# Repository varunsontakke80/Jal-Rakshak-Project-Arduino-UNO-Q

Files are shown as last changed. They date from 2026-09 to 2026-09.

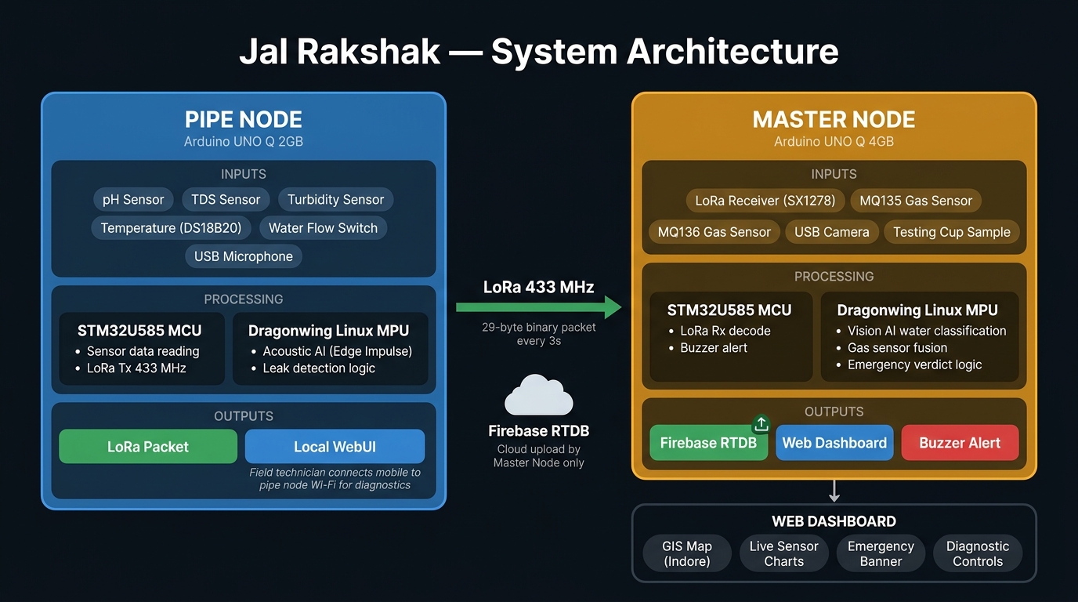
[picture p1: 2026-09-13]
Images/Jal_Rakshak_System_Architecture_v3.jpg

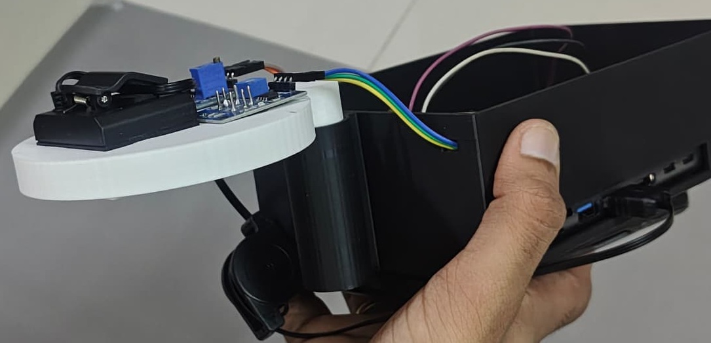
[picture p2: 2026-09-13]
Images/Data collectionsetup MN.jpeg

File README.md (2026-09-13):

# 💧 Jal Rakshak: AI-Powered Municipal Water Security & Pipeline Integrity Network

**Jal Rakshak** ("Water Protector") is a decentralized, dual-tier physical AI water security and acoustic leak detection system designed to safeguard municipal drinking water distribution networks against underground transit contamination, sewage cross-ingress, and silent pipeline bursts.

Addressing the critical "last-mile" vulnerability between centralized water treatment plants and residential taps, Jal Rakshak continuously monitors subterranean pipes using autonomous edge nodes and provides municipal field engineers with a handheld AI diagnostic gateway terminal.

---

## 📌 System Architecture & Core Concept

Municipal water networks frequently suffer from negative pressure events, soil shifting, and aging infrastructure. When an underground potable water pipe develops a leak adjacent to a sewage line or open drain, contaminated water is siphoned into the drinking supply.

Jal Rakshak eliminates reliance on delayed manual complaints and sporadic lab tests through a two-tier physical AI architecture:

```text
+-------------------------------------------------------------------------+
|                      Underground Pipe Node (Field)                      |
|  - ESP32 Dual-Core Controller (Solar / Battery / Energy Harvesting)     |
|  - INMP441 I2S Microphone -> TinyML 1D-CNN (Acoustic Leak Detection)    |
|  - Multi-Sensor Array: pH, Temp-Compensated TDS, Turbidity, Temp, Flow  |
|  - SX1278 LoRa Transceiver (433 MHz Binary Telemetry Uplink)            |
+-------------------------------------------------------------------------+
                                    │
                         [ 433 MHz LoRa Radio Link ]
                         [ 28-Byte Packed Struct   ]
                                    │
                                    ▼
+-------------------------------------------------------------------------+
|                  Jal Rakshak Master Node (Central Gateway)              |
|                                                                         |
|  [STM32U585 MCU (Zephyr RTOS)]                                          |
|   - Hard Real-Time LoRa Telemetry Ingestion (SX1278 SPI)                |
|   - Dual Gas Sensing (12-bit ADC): MQ135 (NH3) & MQ136 (H2S)            |
|   - Hardware Alert Buzzer & RouterBridge Inter-Core RPC Server          |
|                                                                         |
|  [Qualcomm Dragonwing Linux MPU (Arduino App Lab)]                      |
|   - Edge Impulse Vision-AI Image Classifier (MobileNet EIM)             |
|   - Forensic Testing Cup: UV Fluorescence Analysis                      |
|   - Water Quality Multi-Parametric Safety Verdict Engine                |
|   - Interactive WebUI Dashboard on Port 7000 (Leaflet GIS + Live Charts)|
+-------------------------------------------------------------------------+
```

---

## 🧠 Dual Edge AI Intelligence

Jal Rakshak runs two dedicated machine learning models trained via Edge Impulse directly on edge hardware:

1. **TinyML Acoustic Leak Detection (Pipe Node):**
   - **Hardware:** ESP32 (Core 0, FreeRTOS).
   - **Input:** 16 kHz acoustic vibration stream from an INMP441 I2S MEMS microphone clamped to the pipeline.
   - **Model:** 1D-CNN with MFE/MFCC feature extraction distinguishing background urban traffic noise from the high-frequency acoustic hiss of a pressurized pipe leak.
   - **Latency & Performance:** <20 ms inference latency with high energy efficiency on battery power.

2. **Vision-AI Water Quality Classification (Master Node):**
   - **Hardware:** Qualcomm Dragonwing Linux MPU on the Arduino UNO Q.
   - **Input:** Live camera feed from an enclosed testing cup under controlled UV illumination.
   - **Model:** MobileNet transfer-learning vision classifier (`Jal-Rakshak-Water-Quality-Vision`) deployed as a Linux aarch64 EIM executable.
   - **Function:** Detects organic sewage fluorescence, turbidity shifts, and visible contamination that standard electrochemical probes cannot identify.

---

## 📁 Project Structure & File Guide

The repository is organized by subsystem, hardware engineering files, AI models, and documentation assets:

```text
Jal Rakshak/
├── README.md                           # This project documentation
├── Edge AI Models/                     # Standalone compiled Edge Impulse model artifacts (.eim)
├── Images/                             # Architecture diagrams, flowcharts, and hardware photos
├── Master Node/                        # Arduino UNO Q Gateway & Diagnostic Terminal workspace
├── Pipe Node/                          # Underground monitoring node workspace
└── Video/                              # Demonstrations and AI training process recordings
```

### 1. `Master Node/` (Central Gateway & Field Terminal)
* **`Code Files/Master Node APP/`**: Complete Arduino App Lab application for the Arduino UNO Q:
  * `app.yaml`: App Lab application manifest specifying the Python base environment and Edge Impulse video classification brick (`ei-model-1087722-1`).
  * `python/main.py`: Central coordination server, RouterBridge RPC client, multi-sensor verdict logic, and WebSocket broadcaster.
  * `python/config.py`: Thresholds for WHO drinking water standards (pH, TDS, Turbidity, NH₃, H₂S), pinouts, and network configurations.
  * `sketch/sketch.ino`: High-performance Zephyr RTOS firmware for the STM32U585 MCU. Handles SX1278 LoRa reception, MQ135/MQ136 gas ADC sampling, active buzzer alert control, and RouterBridge RPC endpoints.
  * `sketch/sketch.yaml`: Arduino sketch dependency configuration specifying platform and libraries.
  * `assets/`: Web dashboard frontend (`index.html`, `style.css`, `app.js`) featuring real-time GIS pipe map, live telemetry graphs, and forensic testing cup controls.
* **`Code Files/Master Node APP.zip`**: Compressed App Lab package ready for direct import into the Arduino App Lab IDE.
* **`PCB Files/`**:
  * `Schematic_Jal-Rakshak-Master-Node_2026-09-11.png`: Complete Master Node electrical schematic.
  * `PCB_Jal Rakshak Master node.png`: Board layout and trace routing diagram.
  * `Jal Rakshak master Node PCB traces to print.pdf`: Printable 1:1 scale PCB artwork for chemical etching.
* **`CAD Files/`**:
  * `Jal Rakshak Master Node Case.3mf`: 3D printable chassis for the Arduino UNO Q, testing cup chamber, and sensor mountings.
  * `Master Node CAD image.png`, `Slicing SS1.png`, `Slicing SS2.png`: 3D renders and slicer configurations.
* **`Steps to assembly/`**: Step-by-step photographic assembly guide (1.jpeg – 14.jpeg, PCB photos) for component soldering, wiring, and enclosure fitting.
* **`Master Node components.jpeg`**: Photographic overview of all Master Node hardware components.

### 2. `Pipe Node/` (Underground Sensing Station)
* **`Code Files/JalRakshakPipeNode/`**:
  * `sketch/sketch.ino`: ESP32 firmware integrating the Edge Impulse acoustic inference library, analog sensor acquisition (pH, TDS, Turbidity, DS18B20 1-Wire temperature), optical water presence sensing, and 28-byte binary LoRa transmission.
  * `sketch/sketch.yaml`: Dependency configuration for the ESP32 platform.
* **`Code Files/JalRakshakPipeNode.zip`**: Ready-to-deploy archive of the Pipe Node firmware.
* **`PCB Files/`**:
  * `Schematic_Jal-Rakshak-Pipe-Node_2026-09-11.png`: Sensor integration and power management schematic.
  * `Sensor PCB Front.jpg` & `Sensor PCB Back.jpg`: High-resolution photographs of the custom double-sided sensor conditioning board.
* **`CAD Files/`**:
  * `Pipe Node sensor case Final Design.3mf`: In-pipe waterproof sensor chamber for water immersion probes.
  * `Pipe_Node_PCB and MIC Case.3mf`: External acoustic clamp housing holding the ESP32, LoRa module, and INMP441 microphone against the pipe wall.
  * `Pipe Node Sensor Case.png`, `Pipe node Case .png`, `Slicing SS 1.png`, `Slicing SS 2.png`: 3D CAD visualizations and slicing guidelines.
* **`Sound data/`**:
  * `water leak sounds/`: Recorded audio dataset of pressurized water pipe pinhole and crack leaks used for model training.
  * `Noise/`: Environmental baseline recordings (traffic noise, soil dampening, motor hums) used for negative training samples.
* **`Steps to assembly/`**: Comprehensive assembly photographic log (1.jpeg – 20.jpeg, EdgeAI setup guides) showing probe sealing, pipe clamp mounting, and PCB assembly.
* **`Pipe Node Componenets.jpeg` & `Pipe Node sensors.jpeg`**: Visual inventory of all Pipe Node electronics, probes, and mechanical hardware.

### 3. `Edge AI Models/`
* **`jal-rakshak-acoustic-leak-detection-linux-aarch64-v12-impulse-#1.eim`**: Edge Impulse acoustic classification model compiled for aarch64 Linux systems.
* **`jal-rakshak-water-quality-vision-linux-aarch64-v3-impulse-#1.eim`**: Edge Impulse vision classification model compiled for the Qualcomm Dragonwing MPU on the Arduino UNO Q.

### 4. `Images/`
* High-resolution system diagrams and visuals:
  * `Jal_Rakshak_System_Architecture_v3.jpg`: Full end-to-end hardware and network architecture diagram.
  * `Jal_Rakshak_Master_Node_Code_Flowchart.jpg` / `.png`: Operational flow of the dual-processor Master Node firmware and Python runtime.
  * `Jal_Rakshak_Pipe_Node_Code_Flowchart.jpg`: Sensing, TinyML inference, and LoRa transmission logic of the Pipe Node.
  * `Bhagirathpura.png`, `pipeblast.png`, `pipeblast3.png`: Ground truth case study photos demonstrating urban pipeline failure mechanisms.
  * `lorapic.jpg`, `USBc Mic.png`, `Usb C hub.png`, `usb cam.png`, `Data collectionsetup MN.jpeg`: Peripheral and lab testing setup photos.

### 5. `Video/`
* **`Master Node Edge AI making.mp4`**: Demonstration of the Master Node testing cup setup, camera alignment, and Edge Impulse model deployment.
* **`Pipe Node Edge AI Data Collection Process.mp4`**: Acoustic data recording methodology, sensor pod immersion testing, and model training workflow.

---

## 🔌 Hardware Bill of Materials (BOM)

| Subsystem | Component | Specifications / Role |
|---|---|---|
| **Master Gateway** | **Arduino UNO Q (ABX00087)** | Dual-core processor: STM32U585 MCU (Cortex-M33) + Qualcomm Dragonwing Linux MPU |
| **Master Gateway** | **SX1278 LoRa Module (Ra-01)** | 433 MHz SPI LoRa transceiver for long-range packet reception |
| **Master Gateway** | **USB 2.0 HD Camera** | Testing Cup Vision-AI sample image acquisition |
| **Master Gateway** | **UV LED Array (395–405 nm)** | Fluorescent excitation of organic sewage matter |
| **Master Gateway** | **MQ135 Gas Sensor** | Airborne Ammonia ($NH_3$) and sewage gas marker detection |
| **Master Gateway** | **MQ136 Gas Sensor** | Hydrogen Sulfide ($H_2S$) toxic sewage gas detection |
| **Master Gateway** | **5V Active Buzzer** | High-decibel audible emergency alarm for contamination alerts |
| **Pipe Node** | **ESP32 Development Board** | 240 MHz dual-core microcontroller with FreeRTOS |
| **Pipe Node** | **INMP441 I2S MEMS Mic** | Ultra-low noise digital microphone clamped to pipe wall for acoustic leak sensing |
| **Pipe Node** | **SX1278 LoRa Module (Ra-01)** | 433 MHz SPI LoRa transceiver for subterranean packet transmission |
| **Pipe Node** | **Analog pH Sensor & Probe** | Electrochemical hydrogen-ion activity measurement (0–14 pH) |
| **Pipe Node** | **Analog TDS Sensor Kit** | Total Dissolved Solids / mineral conductivity measurement (0–1000 ppm) |
| **Pipe Node** | **Optical Turbidity Sensor** | Nephelometric suspended particulate detection (0–3000 NTU) |
| **Pipe Node** | **DS18B20 Temp Sensor** | Stainless-steel waterproof 1-Wire sensor for dynamic TDS temperature compensation |
| **Pipe Node** | **Optical Liquid Level Sensor** | Non-invasive verification of water presence vs. air-pocket dry conditions |
| **Power** | **3.7V 18650 / LiPo Cells + Solar** | Lithium battery buffering paired with solar/mini-hydro energy harvesting |
| **Enclosures** | **Custom 3D-Printed Housings** | In-pipe water-sealed sensor chamber & external acoustic clamp chassis |

---

## 🚀 Deployment & Operation

### 1. Flashing the Underground Pipe Node (ESP32)
1. Open the Arduino IDE and ensure the **ESP32 by Espressif Systems** board package is installed.
2. Open the sketch located at:
   ```text
   Pipe Node/Code Files/JalRakshakPipeNode/sketch/sketch.ino
   ```
3. Install required libraries via the Arduino Library Manager:
   - `LoRa` (by Sandeep Mistry)
   - `OneWire` & `DallasTemperature`
   - Edge Impulse inferencing library
4. Select board **ESP32 Dev Module**, verify GPIO connections to the sensors and LoRa transceiver, and flash over USB.

### 2. Running the Master Node (Arduino UNO Q)
1. Connect the **Arduino UNO Q** to your local network via Wi-Fi or Ethernet.
2. Launch **Arduino App Lab** and open the application directory:
   ```text
   Master Node/Code Files/Master Node APP
   ```
3. Arduino App Lab automatically parses `app.yaml`, launches the `python-apps-base` container, and initialises the `ei-models-runner` container with the Edge Impulse vision model.
4. The STM32U585 sketch (`sketch/sketch.ino`) is automatically compiled and uploaded to the MCU over the internal bridge.
5. Open your web browser on any device on the same local network:
   ```text
   http://<arduino-uno-q-ip>:7000
   ```
6. The dashboard displays real-time telemetry from up to 4 pipe nodes, live gas concentration values, and interactive controls for the forensic water testing cup.

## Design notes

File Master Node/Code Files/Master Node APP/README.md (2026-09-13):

# 💧 Jal Rakshak Master Node : Decentralized Water Quality Monitoring System
## Master Node Application — Arduino App Lab Bricks

> Real-Time Water Quality Forensic Gateway & Underground Pipeline Network Monitor.  

---

## 🌟 Overview & Features

This project connects the **Qualcomm Dragonwing MPU (Linux)** and **STM32U585 MCU** on the Arduino UNO Q with containerized App Lab Bricks:

1. **`arduino:video_image_classification` Brick**:
   - Runs live video classification using your custom Edge Impulse trained model (`good_water` vs `bad_water`).
   - Streams live camera video feed directly on port `4912` (`/embed`) with bounding boxes/classification overlays.
2. **`arduino:web_ui` Brick**:
   - Hosts a mobile-responsive WebSocket dashboard directly on port `7000` from `assets/`.
   - Access from your smartphone, tablet, or PC browser: `http://<board-ip>:7000`.
3. **Dual-Core STM32 MCU & RouterBridge**:
   - **LoRa 433 MHz** receiver for Pipe Nodes 1–4 telemetry (pH, TDS, turbidity, temperature, leak acoustic alert, emergency flags).
   - **MQ135 (NH₃)** and **MQ136 (H₂S)** gas sensors for biochemical sewage contamination detection.
   - **Buzzer** alarm control.
4. **Google Firebase Realtime Database**:
   - Real-time cloud synchronization for pipeline nodes and forensic water test logs.

---

## 📱 Mobile Web Access (Same WiFi)

1. Connect your phone or laptop to the same WiFi network as your Arduino UNO Q.
2. Open your mobile browser and navigate to:
   ```
   http://<board-ip>:7000
   ```
   *(Example: `http://192.168.1.50:7000` or `http://arduino-uno-q.local:7000`)*

---

## 📁 Project Structure

```
Master Node APP/
├── app.yaml               # App Lab manifest (declares video_image_classification & web_ui bricks)
├── README.md              # Project documentation and deployment guide
│
├── sketch/                # MCU Firmware (STM32U585)
│   ├── sketch.ino         # LoRa SX1278 (433MHz), MQ135/136 ADC, Buzzer, RouterBridge
│   └── sketch.yaml        # Board profile (arduino:zephyr) and pinned library dependencies
│
├── python/                # MPU Application (Qualcomm Dragonwing Linux)
│   ├── main.py            # App Lab Bricks coordinator, RouterBridge listener, Firebase uplink, App.run()
│   ├── config.py          # Firebase Realtime Database credentials
│   └── requirements.txt   # Python dependencies (requests)
│
├── assets/                # WebUI Brick Frontend (served on Port 7000)
│   ├── index.html         # Responsive tabbed dashboard (Pipe Nodes, Water Cup Test, Diagnostics)
│   ├── style.css          # Dark-theme mobile-first stylesheet
│   ├── app.js             # WebUI client (WebSocket events, threshold slider, gas trigger)
│   ├── libs/
│   │   ├── arduino.js     # Official Arduino WebUI client SDK
│   │   └── socket.io.min.js
│   └── img/               # Icons and graphics
│
└── models/                # Edge Impulse ML Models
    └── auqtest-linux-aarch64-v1-impulse-#1.eim   # Custom water quality model
```

---

## 🔌 Hardware Wiring & Pin Mapping

| Peripheral | Board Pin | Type | Function |
|---|---|---|---|
| **LoRa SCK** | D13 | SPI | SX1278 SPI Clock |
| **LoRa MISO** | D12 | SPI | SX1278 SPI MISO |
| **LoRa MOSI** | D11 | SPI | SX1278 SPI MOSI |
| **LoRa CS (NSS)** | D10 | GPIO | Chip Select |
| **LoRa RST** | D9 | GPIO | Reset |
| **LoRa DIO0** | D2 | GPIO (Interrupt) | Packet Received Flag |
| **MQ135 (Ammonia)** | A0 | Analog ADC (3.3V) | NH₃ Gas Sensor (via 10k/20k divider) |
| **MQ136 (H₂S)** | A1 | Analog ADC (3.3V) | H₂S Gas Sensor (via 10k/20k divider) |
| **Buzzer** | D7 | Digital Output | Active Alarm (HIGH = ON) |
| **USB Camera** | USB-C Hub | V4L2 USB | Water Testing Cup Visual AI |

> ⚠️ **Voltage Note**: The STM32U585 GPIOs operate at **3.3V**. Ensure MQ sensors use the 10kΩ + 20kΩ voltage divider from the 5V sensor output.

---

## 🚀 How to Run in Arduino App Lab

### Step 1 — Open the App in App Lab IDE
1. Connect your **Arduino UNO Q** to your computer via USB-C.
2. Launch the **Arduino App Lab** application.
3. Click **Open App** and select the `Master Node APP` folder.

### Step 2 — Model Setup
- In App Lab, the `app.yaml` will automatically detect the `video_image_classification` Brick.
- You can select your imported Edge Impulse water model (`auqtest-linux-aarch64-v1-impulse-#1`) in the brick settings.

### Step 3 — Configure Cloud Database
- Edit `python/config.py` with your Firebase Realtime Database URL & secret key.

### Step 4 — Run!
- Click the **Run** button at the top of App Lab.
- App Lab compiles the MCU sketch, launches the Brick containers, and opens the Web UI.
- On your phone, visit `http://<board-ip>:7000` to interact with the system live!

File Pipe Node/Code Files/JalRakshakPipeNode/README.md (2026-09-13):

# Jal Rakshak Pipe Node — Application Architecture & Code Structure

**Platform:** Arduino UNO Q (Dual-Processor: Qualcomm Dragonwing QRB2210 MPU + STM32U585 MCU)

---

## 1. System Overview

The **Jal Rakshak Pipe Node** is an intelligent, edge-computing underground water security monitor installed directly along municipal pipeline segments. It combines:
1. **Multi-Parameter Physical Sensor Acquisition** on the STM32 MCU.
2. **Sub-surface Acoustic Leak Detection** using Edge AI (TinyML) on the Qualcomm Dragonwing Linux MPU.
3. **Long-Range Telemetry Uplink** via 433 MHz LoRa to the Master Node Gateway.
4. **Local Mobile Diagnostic WebUI** on port 7000 for field technician maintenance without requiring internet access.

> **CRITICAL ARCHITECTURAL DESIGN**: All field telemetry is transmitted exclusively via LoRa (SX1278) to the Master Node, which handles cloud synchronisation.

---

## 2. Dual-Processor Division of Responsibility

| Subsystem | Processor | Environment | Key Responsibilities |
| :--- | :--- | :--- | :--- |
| **Microcontroller (MCU)** | STM32U585 (ARM Cortex-M33) | Zephyr RTOS / Arduino C++ (sketch/) | Real-time ADC sensor sampling (pH, TDS, Turbidity, Temp, Flow switch); LoRa SX1278 binary packet serialization & RF transmission; RouterBridge RPC endpoints. |
| **Microprocessor (MPU)** | Qualcomm Dragonwing QRB2210 (Quad Cortex-A53, 2GB RAM) | Debian Linux / Python 3.13 (python/) | High-speed audio capture via ALSA (plughw:0,0); continuous Edge Impulse inference (Leak vs Noise); temporal alert filtering; diagnostic WebSocket WebUI. |

---

## 3. Communication Interface (RouterBridge RPC)

The MPU and MCU communicate via high-speed shared memory RPC (Arduino_RouterBridge):

- **
ead_sensors()** (MCU provides, MPU calls every 3s):
  Returns CSV string: 
odeId,latitude,longitude,ph,tds,turbidity,temperature,waterPresence,leakAlert,emergencyFlag
- **leak_alert(bool)** (MPU notifies MCU):
  Triggered when Edge AI detects acoustic cavitation/leak with $\ge 75\%$ confidence for 2 consecutive windows. Causes MCU to immediately assert the emergency flag and force an unscheduled LoRa transmission.
- **	rigger_lora_tx** (MPU notifies MCU):
  Allows field technicians to trigger an immediate manual LoRa transmission test from the diagnostic WebUI.
- **sensor_update** (MCU notifies MPU):
  Emitted after every periodic LoRa transmission so the local WebUI reflects the exact telemetry sent to the Master Node.

---

## 4. File Structure

`	ext
JalRakshakPipeNode/
├── app.yaml               # App Lab manifest (audio_classification & web_ui bricks)
├── README.md              # Complete architecture and operation documentation
├── assets/
│   ├── index.html         # Responsive diagnostic dashboard HTML
│   ├── style.css          # Dark-mode industrial cyber-clean CSS
│   ├── app.js             # Client WebSocket telemetry & Edge AI bar animator
│   └── libs/
│       ├── arduino.js     # Official Arduino App Lab WebUI client
│       └── socket.io.min.js# Offline Socket.IO client library
├── models/
│   └── README.md          # Edge Impulse project & class documentation
├── python/
│   ├── main.py            # Main MPU application (AI inference hook & bridge logic)
│   └── config.py          # Node identity & deployment parameters
└── sketch/
    ├── sketch.ino         # STM32 MCU firmware (ADC acquisition & LoRa driver)
    └── sketch.yaml        # Zephyr platform & library dependency manifest
`

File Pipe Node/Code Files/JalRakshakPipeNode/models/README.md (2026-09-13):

# Jal Rakshak Pipe Node — Edge AI Acoustic Leak Detection Model

This folder documents the Edge Impulse model configuration for the underground acoustic leak detection system running on the Arduino UNO Q (Qualcomm Dragonwing QRB2210 MPU, Linux aarch64).

---

## 1. Edge Impulse Project Details

- **Project Name:** Jal-Rakshak-Acoustic-Leak-Detection
- **Owner / Project ID:** 
arunsontakke80 / 1022382
- **Deployment Version:** 
11 (ei-model-1022382-1)
- **Application:** Real-time acoustic frequency analysis of pipe vibrations to detect subterranean water leaks and cavitation
- **Target Hardware:** Arduino UNO Q (Qualcomm Dragonwing QRB2210, Linux aarch64)
- **Input Peripheral:** USB Microphone on ALSA hardware card plughw:0,0

---

## 2. Model Classes & Classification

The trained model classifies 1-second audio windows into 2 distinct classes:

| Class | Label in EI | Description | System Action |
|---|---|---|---|
| **1** | Leak | Acoustic signature of pressurized water escaping a pipe fissure, cavitation hiss, or turbulent pipe breach | Increment consecutive counter; trigger emergency LoRa packet when confidence >= 75% for 2 consecutive windows |
| **2** | Noise | Normal ambient background sound, pump hum, laminar water flow, or surface environmental noise | Clear leak alert status; maintain normal telemetry cycle |

---

## 3. Impulse Design Parameters

- **Time series data:** 1000 ms (1.0 s) window size, 500 ms sliding window stride
- **Frequency:** 16,000 Hz (16 kHz), 1 channel (mono)
- **Input Features:** 16,000 features per inference window
- **DSP Block:** MFE (Mel-Frequency Energy)
- **Learning Block:** 1D / 2D Convolutional Neural Network (continuous audio classification)

---

## 4. App Lab Architecture & Continuous Inference

In Arduino App Lab, the rduino:audio_classification brick:
1. Automatically launches the Edge Impulse runner container (ei-audio-classifier-runner:1337).
2. Streams audio captured from ALSA plughw:0,0 (16 kHz mono) into the model.
3. python/main.py hooks sc.infer_from_features to intercept every single inference slice (~400 ms) directly from the runner.
4. Raw probabilities for both Leak and Noise are streamed in real time over WebSocket to the local diagnostic WebUI (http://<ip>:7000).
5. When Leak >= 0.75 for 2 consecutive windows, python/main.py notifies the STM32 MCU via Bridge RPC (leak_alert), forcing an immediate emergency LoRa transmission to the Master Node.

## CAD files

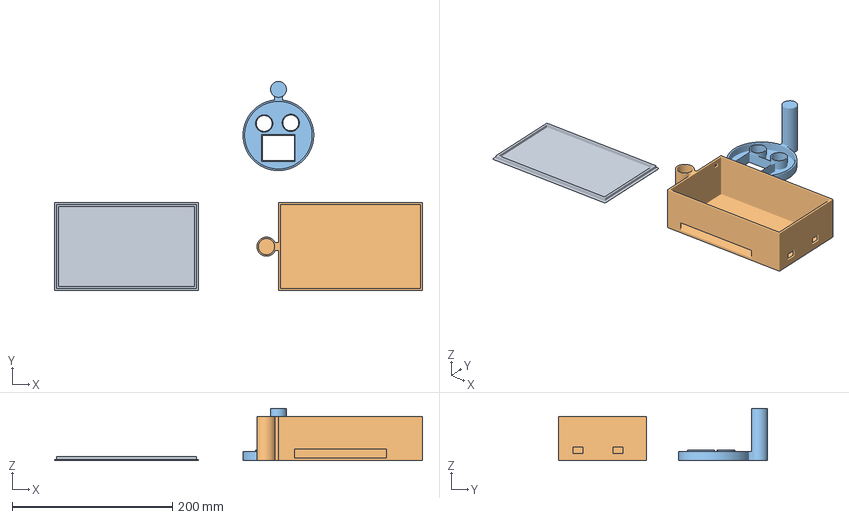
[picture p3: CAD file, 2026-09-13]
Master Node/CAD Files/Jal Rakshak Master Node Case.3mf
460.0 x 261.6 x 65.0 mm

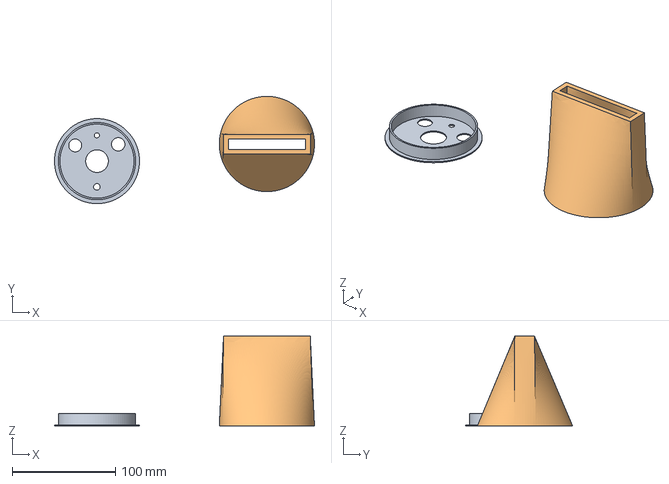
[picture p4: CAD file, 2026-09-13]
Pipe Node/CAD Files/Pipe Node sensor case Final Design.3mf
252.3 x 104.1 x 87.0 mm

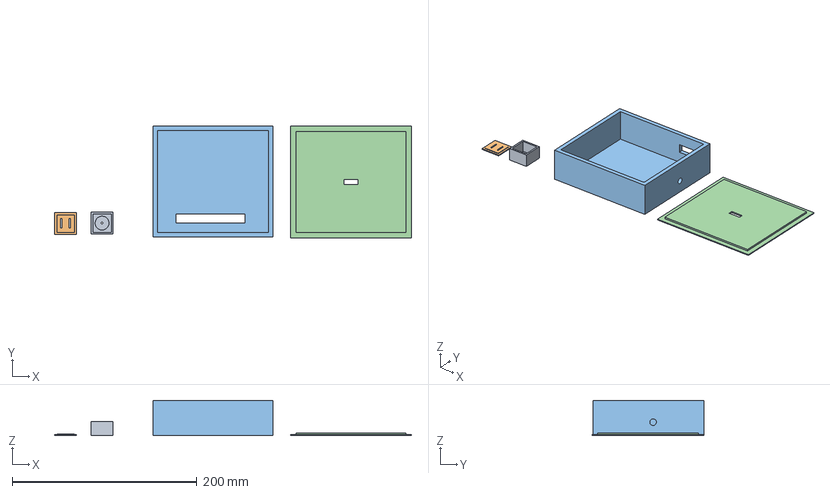
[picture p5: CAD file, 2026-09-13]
Pipe Node/CAD Files/Pipe_Node_PCB and MIC Case.3mf
386.5 x 121.0 x 38.0 mm

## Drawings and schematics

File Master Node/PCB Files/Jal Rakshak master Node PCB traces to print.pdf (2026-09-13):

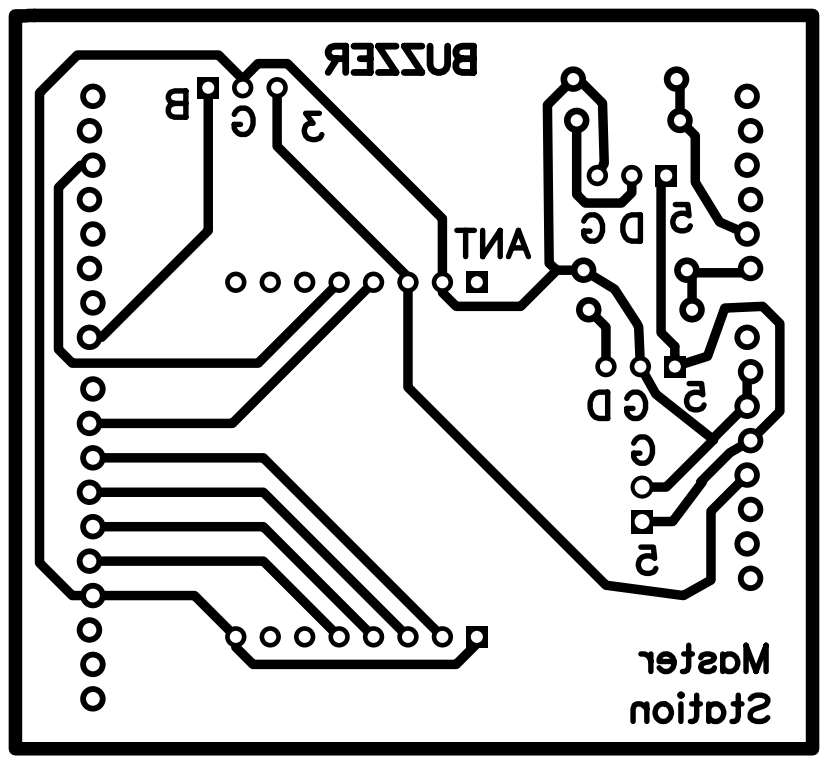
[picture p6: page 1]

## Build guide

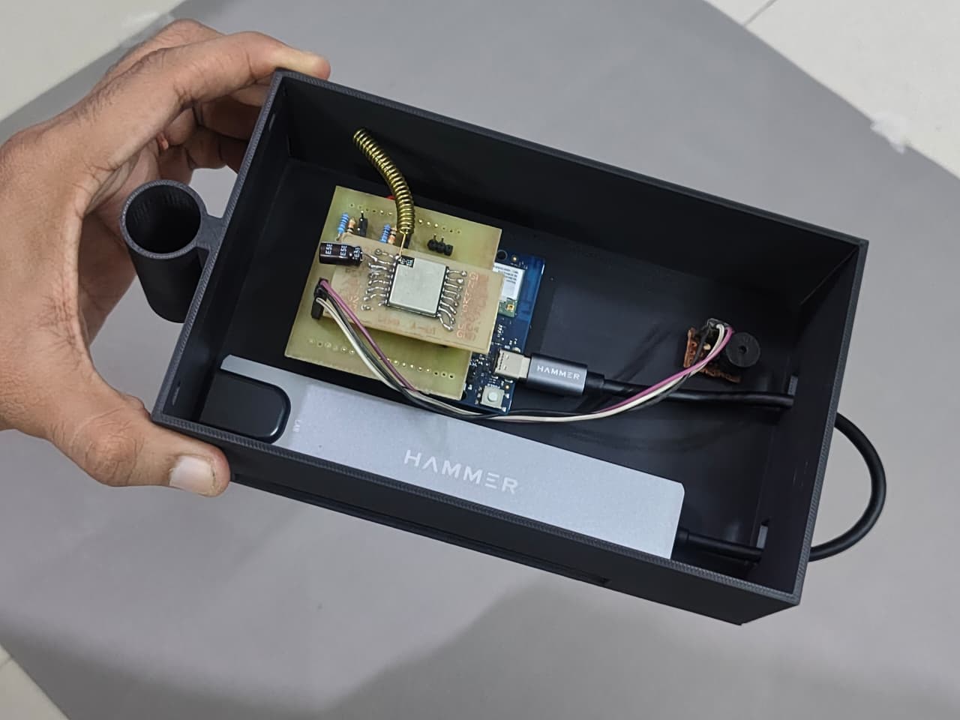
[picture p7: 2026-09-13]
Master Node/Steps to assembly/8.jpeg

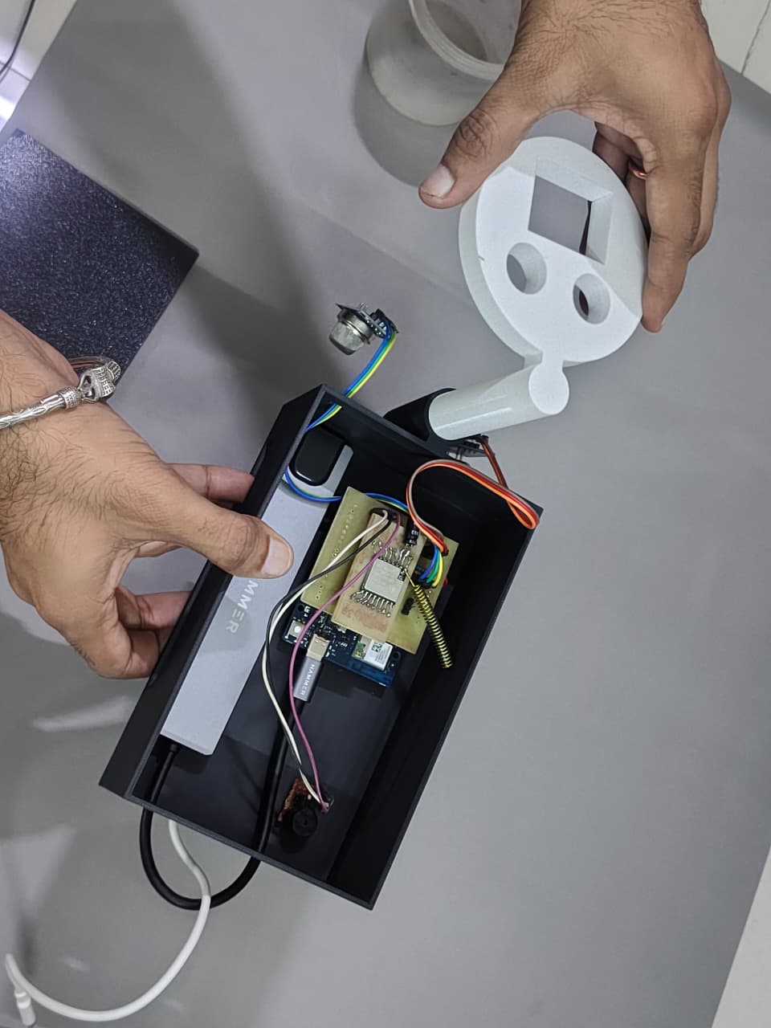
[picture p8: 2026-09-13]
Master Node/Steps to assembly/11.jpeg

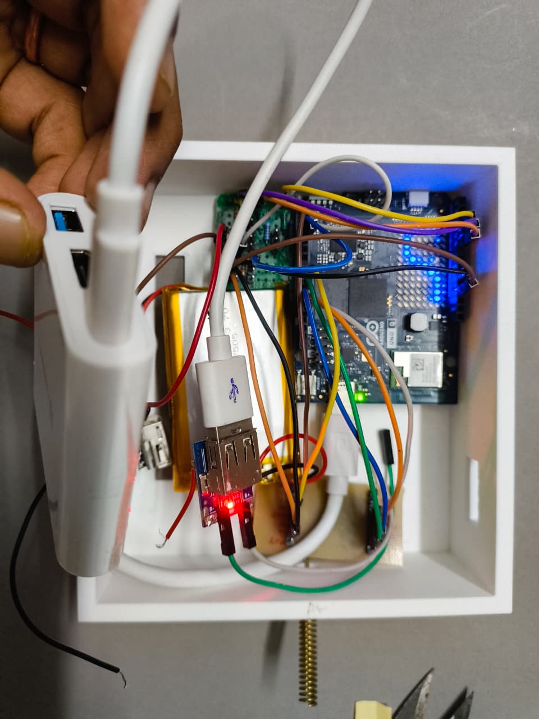
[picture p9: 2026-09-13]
Pipe Node/Steps to assembly/16.1.jpeg

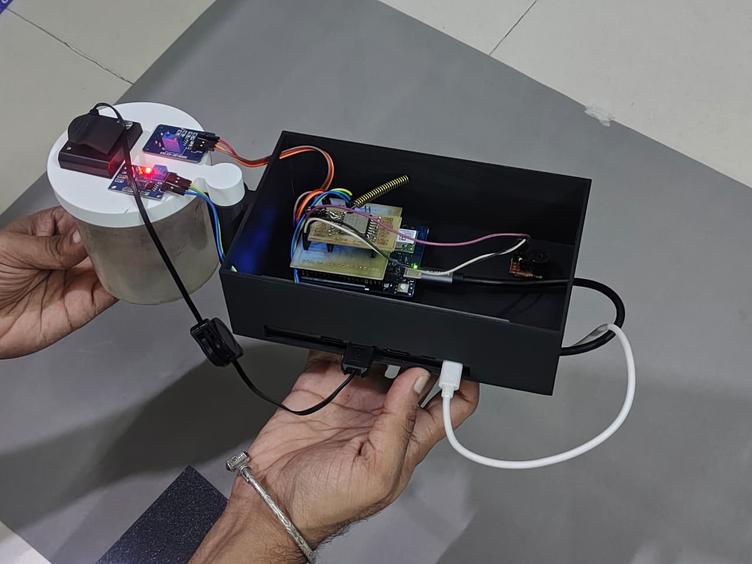
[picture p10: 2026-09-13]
Master Node/Steps to assembly/12.jpeg

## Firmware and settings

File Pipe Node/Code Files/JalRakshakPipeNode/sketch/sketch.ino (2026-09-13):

/**
 * Jal Rakshak Pipe Node — Arduino UNO Q (STM32U585 MCU, Zephyr RTOS)
 *
 * Responsibilities (MCU side):
 *   - Read water quality sensors: pH (A0), TDS (A1), Turbidity (A2)
 *   - Read DS18B20 water temperature via 1-Wire (D4)
 *   - Detect water flow switch (D3, interrupt)
 *   - Transmit 28-byte binary TelemetryPayload over LoRa (SX1278, 433 MHz)
 *   - Expose Bridge RPC endpoints for MPU (main.py) to:
 *       - read_sensors()    → returns CSV of all sensor values
 *       - trigger_lora_tx() → forces an immediate LoRa transmission
 *   - Receive leak_alert notifications from MPU (acoustic AI result)
 *     and fold leakAlert flag into the next LoRa transmission
 *
 * Sensors pinout (all analog sensors must go through 10k/20k voltage divider
 * because sensors output 0-5V but UNO Q ADC pins are 3.3V max):
 *   A0 = pH sensor (analog, 0-5V scaled to 0-3.3V)
 *   A1 = TDS sensor (analog, 0-5V scaled to 0-3.3V)
 *   A2 = Turbidity sensor (analog, 0-5V scaled to 0-3.3V)
 *   D4 = DS18B20 data (1-Wire, 4.7k pull-up to 3.3V)
 *   D3 = Water flow switch (digital input, interrupt on CHANGE)
 * LoRa SX1278 (SPI):
 *   D13 = SCK, D12 = MISO, D11 = MOSI, D10 = CS, D9 = RST, D2 = DIO0
 *
 * Author: Varun Sontakke — Jal Rakshak Project
 */

#include <SPI.h>
#include <LoRa.h>
#include <OneWire.h>
#include <DallasTemperature.h>
#include <Arduino_RouterBridge.h>

// ── LoRa SX1278 Pinout ─────────────────────────────────────────────────────
#define LORA_SCK    13
#define LORA_MISO   12
#define LORA_MOSI   11
#define LORA_CS     10
#define LORA_RST     9
#define LORA_DIO0    2

// ── Water Quality Sensor Pins (analog, through voltage divider) ─────────────
#define PIN_PH          A0
#define PIN_TDS         A1
#define PIN_TURBIDITY   A2
#define PIN_DS18B20     4   // 1-Wire data, 4.7k pull-up to 3.3V
#define PIN_FLOW_SWITCH 3   // Digital input w/ interrupt

// ── ADC & voltage constants ─────────────────────────────────────────────────
#define VOLTAGE_RESOLUTION      3.3f
#define ADC_MAX                 4095.0f  // 12-bit ADC
// The voltage divider (10kΩ top / 20kΩ bottom) makes Vadc = Vsensor * (20/(10+20)) = 0.667 * Vsensor
// So Vsensor = Vadc * 1.5  (multiply measured voltage by 1.5 to recover true 0-5V sensor output)
#define VOLTAGE_DIVIDER_FACTOR  1.5f

// ── pH calibration ──────────────────────────────────────────────────────────
#define PH_M    -5.70f
#define PH_B    17.24f

// ── Node Identity ───────────────────────────────────────────────────────────
#define NODE_ID       1          // Change to 2/3/4 for other nodes
#define NODE_LAT      22.7196f   // Update GPS for deployment location
#define NODE_LON      75.8577f

// ── Telemetry timing ────────────────────────────────────────────────────────
#define TELEMETRY_INTERVAL_MS  3000   // 3-second heartbeat LoRa Tx
#define SENSOR_SAMPLE_COUNT    5      // Oversample & average for noise rejection

// ── TelemetryPayload struct (packed binary for LoRa) ───────────────────────
#pragma pack(push, 1)
struct TelemetryPayload {
    uint8_t  nodeId;        // 1 byte
    float    latitude;      // 4 bytes
    float    longitude;     // 4 bytes
    float    ph;            // 4 bytes
    float    tds;           // 4 bytes
    float    turbidity;     // 4 bytes
    float    temperature;   // 4 bytes
    bool     waterPresence; // 1 byte
    bool     leakAlert;     // 1 byte
    bool     emergencyFlag; // 1 byte
    // Total = 28 bytes
};
#pragma pack(pop)

// ── Sensor objects ──────────────────────────────────────────────────────────
OneWire oneWire(PIN_DS18B20);
DallasTemperature ds18b20(&oneWire);

// ── Shared state ────────────────────────────────────────────────────────────
volatile bool waterPresence    = true;     // Default: active flow in pipe (safe baseline)
bool          leakAlert        = false;    // Set by MPU Bridge notify
bool          forceTx          = false;    // Force immediate LoRa Tx
unsigned long lastTxMs         = 0;

// ── Flow switch interrupt (standard Arduino ISR on STM32 / Zephyr) ───────────
void onFlowChange() {
    waterPresence = (digitalRead(PIN_FLOW_SWITCH) == LOW);
}

// ── ADC helpers ─────────────────────────────────────────────────────────────
float readVoltageSensor(int pin) {
    long sum = 0;
    for (int i = 0; i < SENSOR_SAMPLE_COUNT; i++) {
        sum += analogRead(pin);
        delayMicroseconds(200);
    }
    float raw = (float)sum / SENSOR_SAMPLE_COUNT;
    float vadc = (raw / ADC_MAX) * VOLTAGE_RESOLUTION;    // ADC voltage (0-3.3V)
    float vsensor = vadc * VOLTAGE_DIVIDER_FACTOR;         // True sensor voltage (0-5V)
    return vsensor;
}

// ── pH conversion ───────────────────────────────────────────────────────────
float readPH() {
    float v = readVoltageSensor(PIN_PH);
    // When probe is disconnected or floating (open-circuit near 0V or >4.85V),
    // default to normal safe drinking water pH (7.24)
    if (v < 0.25f || v > 4.85f) {
        return 7.24f;
    }
    float ph = PH_M * v + PH_B;
    ph = constrain(ph, 0.0f, 14.0f);
    return ph;
}

// ── TDS conversion (with temperature compensation) ──────────────────────────
float readTDS(float tempC) {
    float v = readVoltageSensor(PIN_TDS);
    // When probe is disconnected (open-circuit near 0V or >4.85V),
    // default to normal safe drinking water TDS (185.0 ppm)
    if (v < 0.08f || v > 4.85f) {
        return 185.0f;
    }
    float rawTDS = (133.42f * v * v * v - 255.86f * v * v + 857.39f * v) * 0.5f;
    float compensated = rawTDS / (1.0f + 0.02f * (tempC - 25.0f));
    compensated = constrain(compensated, 0.0f, 1500.0f);
    return compensated;
}

// ── Turbidity conversion ─────────────────────────────────────────────────────
float readTurbidity() {
    float v = readVoltageSensor(PIN_TURBIDITY);
    // When probe is disconnected (open-circuit near 0V or >4.85V),
    // default to normal safe drinking water turbidity (8.5 NTU)
    if (v < 0.20f || v > 4.85f) {
        return 8.5f;
    }
    float ntu = -1120.4f * v * v + 5742.3f * v - 4352.9f;
    ntu = constrain(ntu, 0.0f, 3000.0f);
    return ntu;
}

// ── DS18B20 temperature ──────────────────────────────────────────────────────
float readTemperature() {
    ds18b20.requestTemperatures();
    float t = ds18b20.getTempCByIndex(0);
    if (t == DEVICE_DISCONNECTED_C || t < -50.0f || t > 85.0f) {
        t = 25.0f;  // Fallback to 25°C if sensor not connected
    }
    return t;
}

// ── Emergency logic ──────────────────────────────────────────────────────────
bool checkEmergency(float ph, float tds, float turbidity) {
    if (ph < 6.0f || ph > 8.5f)    return true;   // pH out of safe range
    if (tds > 800.0f)               return true;   // TDS above WHO limit
    if (turbidity > 400.0f)         return true;   // Turbidity above WHO limit
    return false;
}

// ── Build and transmit LoRa packet ────────────────────────────────────────────
void transmitTelemetry(float ph, float tds, float turbidity, float temperature,
                       bool waterPres, bool leak, bool emergency) {
    TelemetryPayload pkt;
    pkt.nodeId        = NODE_ID;
    pkt.latitude      = NODE_LAT;
    pkt.longitude     = NODE_LON;
    pkt.ph            = ph;
    pkt.tds           = tds;
    pkt.turbidity     = turbidity;
    pkt.temperature   = temperature;
    pkt.waterPresence = waterPres;
    pkt.leakAlert     = leak;
    pkt.emergencyFlag = emergency;

    LoRa.beginPacket();
    LoRa.write((uint8_t*)&pkt, sizeof(pkt));
    LoRa.endPacket();

    Serial.println("------- LoRa Packet Sent -------");
    Serial.print("Node ID   : "); Serial.println(pkt.nodeId);
    Serial.print("pH        : "); Serial.println(ph, 2);
    Serial.print("TDS       : "); Serial.print(tds, 1); Serial.println(" ppm");
    Serial.print("Turbidity : "); Serial.print(turbidity, 1); Serial.println(" NTU");
    Serial.print("Temp      : "); Serial.print(temperature, 1); Serial.println(" °C");
    Serial.print("Water     : "); Serial.println(waterPres ? "YES" : "NO");
    Serial.print("Leak Alert: "); Serial.println(leak ? "DETECTED!" : "Clear");
    Serial.print("Emergency : "); Serial.println(emergency ? "ACTIVE!" : "Normal");
    Serial.println("--------------------------------");

    // Also notify Bridge so MPU always has latest values
    String csv = String(NODE_ID) + "," +
                 String(NODE_LAT, 6) + "," +
                 String(NODE_LON, 6) + "," +
                 String(ph, 2) + "," +
                 String(tds, 1) + "," +
                 String(turbidity, 1) + "," +
                 String(temperature, 1) + "," +
                 String(waterPres ? 1 : 0) + "," +
                 String(leak ? 1 : 0) + "," +
                 String(emergency ? 1 : 0);
    Bridge.notify("sensor_update", csv);
}

// ── Bridge RPC handlers ────────────────────────────────────────────────────────

// MPU can request current sensor readings (for WebUI display)
String read_sensors(String args) {
    float temp = readTemperature();
    float ph   = readPH();
    float tds  = readTDS(temp);
    float turb = readTurbidity();
    bool wp    = waterPresence;
    bool emg   = checkEmergency(ph, tds, turb);

    return String(NODE_ID) + "," +
           String(NODE_LAT, 6) + "," +
           String(NODE_LON, 6) + "," +
           String(ph, 2) + "," +
           String(tds, 1) + "," +
           String(turb, 1) + "," +
           String(temp, 1) + "," +
           String(wp ? 1 : 0) + "," +
           String(leakAlert ? 1 : 0) + "," +
           String(emg ? 1 : 0);
}

// MPU can force an immediate LoRa transmission
void trigger_lora_tx(String args) {
    forceTx = true;
}

// MPU notifies MCU that acoustic AI detected a leak
void on_leak_alert(bool detected) {
    leakAlert = detected;
    if (detected) {
        forceTx = true;  // Trigger immediate LoRa transmission
        Serial.println("[ACOUSTIC AI] Water leak confirmed by MPU! Triggering emergency Tx.");
    } else {
        Serial.println("[ACOUSTIC AI] Leak cleared by MPU.");
    }
}

// ── Setup ─────────────────────────────────────────────────────────────────────
void setup() {
    Serial.begin(115200);
    delay(2000);

    Serial.println("\n=========================================");
    Serial.println("  Jal Rakshak Pipe Node — Starting");
    Serial.println("=========================================");
    Serial.println("  Board: Arduino UNO Q (2GB RAM Variant)");
    Serial.println("=========================================");

    // DS18B20
    ds18b20.begin();
    Serial.println("DS18B20 1-Wire temperature sensor initialized.");

    // Flow switch interrupt
    pinMode(PIN_FLOW_SWITCH, INPUT_PULLUP);
    attachInterrupt(digitalPinToInterrupt(PIN_FLOW_SWITCH), onFlowChange, CHANGE);
    Serial.println("Flow switch interrupt registered on D3.");

    // 12-bit ADC
    analogReadResolution(12);

    // LoRa initialization
    LoRa.setPins(LORA_CS, LORA_RST, LORA_DIO0);
    if (!LoRa.begin(433E6)) {
        Serial.println("ERROR: LoRa init failed! Check wiring.");
    } else {
        Serial.println("LoRa initialized — 433 MHz ready.");
        LoRa.setSpreadingFactor(7);     // SF7 for low latency
        LoRa.setSignalBandwidth(125E3); // 125 kHz BW
        LoRa.setCodingRate4(5);         // 4/5 coding rate
    }

    // Bridge RPC
    Bridge.begin();
    Bridge.provide("read_sensors",     read_sensors);
    Bridge.provide_safe("trigger_lora_tx", trigger_lora_tx);
    Bridge.provide_safe("leak_alert",  on_leak_alert);
    Serial.println("Bridge RPC handlers registered.");
    Serial.println("Pipe Node ready. Starting telemetry loop.");

    lastTxMs = millis();
}

// ── Main Loop ─────────────────────────────────────────────────────────────────
void loop() {
    unsigned long now = millis();
    bool doTx = forceTx || ((now - lastTxMs) >= TELEMETRY_INTERVAL_MS);

    if (doTx) {
        forceTx = false;
        lastTxMs = now;

        // Read all sensors
        float temperature = readTemperature();
        float ph          = readPH();
        float tds         = readTDS(temperature);
        float turbidity   = readTurbidity();
        bool  waterPres   = waterPresence;
        bool  emergency   = checkEmergency(ph, tds, turbidity) || leakAlert;

        // Transmit LoRa packet
        transmitTelemetry(ph, tds, turbidity, temperature, waterPres, leakAlert, emergency);
    }

    delay(10);
}

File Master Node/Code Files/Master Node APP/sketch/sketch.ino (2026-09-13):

/**
 * Jal Rakshak Master Node — Arduino UNO Q (STM32U585 MCU, Zephyr RTOS)
 * 
 * Responsibilities (MCU side):
 *   - Receives 28-byte binary TelemetryPayload from Pipe Nodes over LoRa (SX1278, 433 MHz)
 *   - Reads biochemical gas sensors: MQ135 (NH3 on A0), MQ136 (H2S on A1) for testing cup
 *   - Controls buzzer alert (D7) for contamination & leak alarms
 *   - Communicates with Dragonwing Linux MPU via RouterBridge (MessagePack RPC & notify)
 *
 * Author: Varun Sontakke — Jal Rakshak Project
 */

#include <SPI.h>
#include <LoRa.h>
#include <Arduino_RouterBridge.h>

// Arduino UNO Q LoRa RA01 Pinout (standard SPI headers)
#define LORA_SCK  13
#define LORA_MISO 12
#define LORA_MOSI 11
#define LORA_CS   10
#define LORA_RST  9
#define LORA_DIO0 2

#define PIN_MQ135 A0
#define PIN_MQ136 A1
#define PIN_BUZZER 7

// ADC & voltage config for raw gas sensor reading
#define VOLTAGE_RESOLUTION 3.3
#define ADC_MAX 4095.0  // 12-bit ADC

// MQ sensor calibration constants (clean air Rs/Ro ratios)
#define MQ135_RL 10.0   // Load resistance in kΩ
#define MQ135_RO 76.63  // Clean air resistance (calibrated)
#define MQ136_RL 10.0
#define MQ136_RO 19.78

#pragma pack(push, 1)
struct TelemetryPayload {
    uint8_t  nodeId;
    float    latitude;
    float    longitude;
    float    ph;
    float    tds;
    float    turbidity;
    float    temperature;
    bool     waterPresence;
    bool     leakAlert;
    bool     emergencyFlag;
};
#pragma pack(pop)

// Non-blocking 3-second buzzer timer
unsigned long buzzerEndTime = 0;
bool buzzerActive = false;

// Buffer for LoRa telemetry polling backup
String latestLoraCsv = "";
bool hasNewLora = false;

void triggerBuzzer(int durationMs) {
    digitalWrite(PIN_BUZZER, HIGH);
    buzzerEndTime = millis() + durationMs;
    buzzerActive = true;
}

void buzzer_control_handler(bool state) {
    if (state) {
        triggerBuzzer(3000);
    } else {
        digitalWrite(PIN_BUZZER, LOW);
        buzzerActive = false;
    }
}

void buzzer_beep_handler(int durationMs) {
    if (durationMs <= 0) durationMs = 3000;
    triggerBuzzer(durationMs);
}

// ── Raw MQ Gas Sensor Reading (No MQUnifiedsensor library) ──────────
// Converts raw ADC reading to sensor resistance Rs
float getResistance(int pin, float rl) {
    int raw = analogRead(pin);
    if (raw == 0) raw = 1; // prevent divide-by-zero
    float voltage = (float)raw / ADC_MAX * VOLTAGE_RESOLUTION;
    float rs = rl * (VOLTAGE_RESOLUTION - voltage) / voltage;
    return rs;
}

// MQ135: NH3 ppm estimation from Rs/Ro ratio
// Using power regression: ppm = A * (Rs/Ro)^B
// Coefficients for NH3: A=102.2, B=-2.473
float readNH3() {
    float rs = getResistance(PIN_MQ135, MQ135_RL);
    float ratio = rs / MQ135_RO;
    if (ratio <= 0.0) return 0.0;
    float ppm = 102.2 * pow(ratio, -2.473);
    if (ppm < 0.0) ppm = 0.0;
    if (ppm > 500.0) ppm = 500.0; // Clamp to sensor max
    return ppm;
}

// MQ136: H2S ppm estimation from Rs/Ro ratio
// Coefficients for H2S: A=40.5, B=-2.15
float readH2S() {
    float rs = getResistance(PIN_MQ136, MQ136_RL);
    float ratio = rs / MQ136_RO;
    if (ratio <= 0.0) return 0.0;
    float ppm = 40.5 * pow(ratio, -2.15);
    if (ppm < 0.0) ppm = 0.0;
    if (ppm > 200.0) ppm = 200.0;
    return ppm;
}

String read_mq_sensors(String args) {
    float nh3 = readNH3();
    float h2s = readH2S();
    return String(nh3, 2) + "," + String(h2s, 2);
}

String get_latest_lora(String args) {
    if (hasNewLora) {
        hasNewLora = false;
        return latestLoraCsv;
    }
    return "";
}

void setup() {
    Serial.begin(115200);
    delay(2000);
    
    Serial.println("\n========================================");
    Serial.println(" Jal Rakshak Master Node — Starting ");
    Serial.println("========================================");
    
    Bridge.begin();
    
    pinMode(PIN_BUZZER, OUTPUT);
    digitalWrite(PIN_BUZZER, LOW);
    
    // LoRa initialization
    LoRa.setPins(LORA_CS, LORA_RST, LORA_DIO0);
    if (!LoRa.begin(433E6)) {
        Serial.println("Starting LoRa failed! Check Wiring.");
    } else {
        Serial.println("LoRa initialized successfully on 433 MHz.");
    }
    
    analogReadResolution(12);

    // Register Bridge RPC handlers
    Bridge.provide("read_mq_sensors", read_mq_sensors);
    Bridge.provide_safe("buzzer_control", buzzer_control_handler);
    Bridge.provide_safe("buzzer_beep", buzzer_beep_handler);
    Bridge.provide("get_latest_lora", get_latest_lora);
    
    Serial.println("Bridge RPC handlers registered.");
}

void loop() {
    // Non-blocking buzzer timer check
    if (buzzerActive && millis() >= buzzerEndTime) {
        digitalWrite(PIN_BUZZER, LOW);
        buzzerActive = false;
    }
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
